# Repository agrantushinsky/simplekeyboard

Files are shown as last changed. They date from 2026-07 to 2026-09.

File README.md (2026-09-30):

# simplekeyboard: 60% Mechanical Keyboard PCB
## Overview
A custom 60% mechanical keyboard 2-layer PCB built around an STM32 microcontroller and USB-C connectivity. The design utilizes I2C IO expanders to simplify matrix trace routing across the board. 

## Current Status (WIP)
Hardware bring-up is actively underway. I identified an error that swapped the SCL and SDA lines on one of the IO expanders. The next step is performing a physical trace bodge to fix the bus so I can finish validating the matrix polling logic.

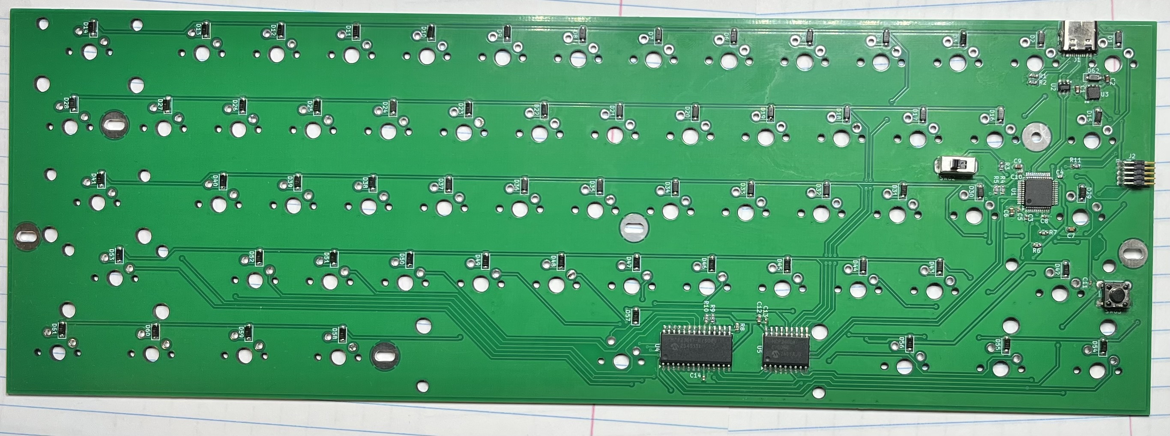
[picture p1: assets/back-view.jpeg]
Back View of PCB


## Schematics
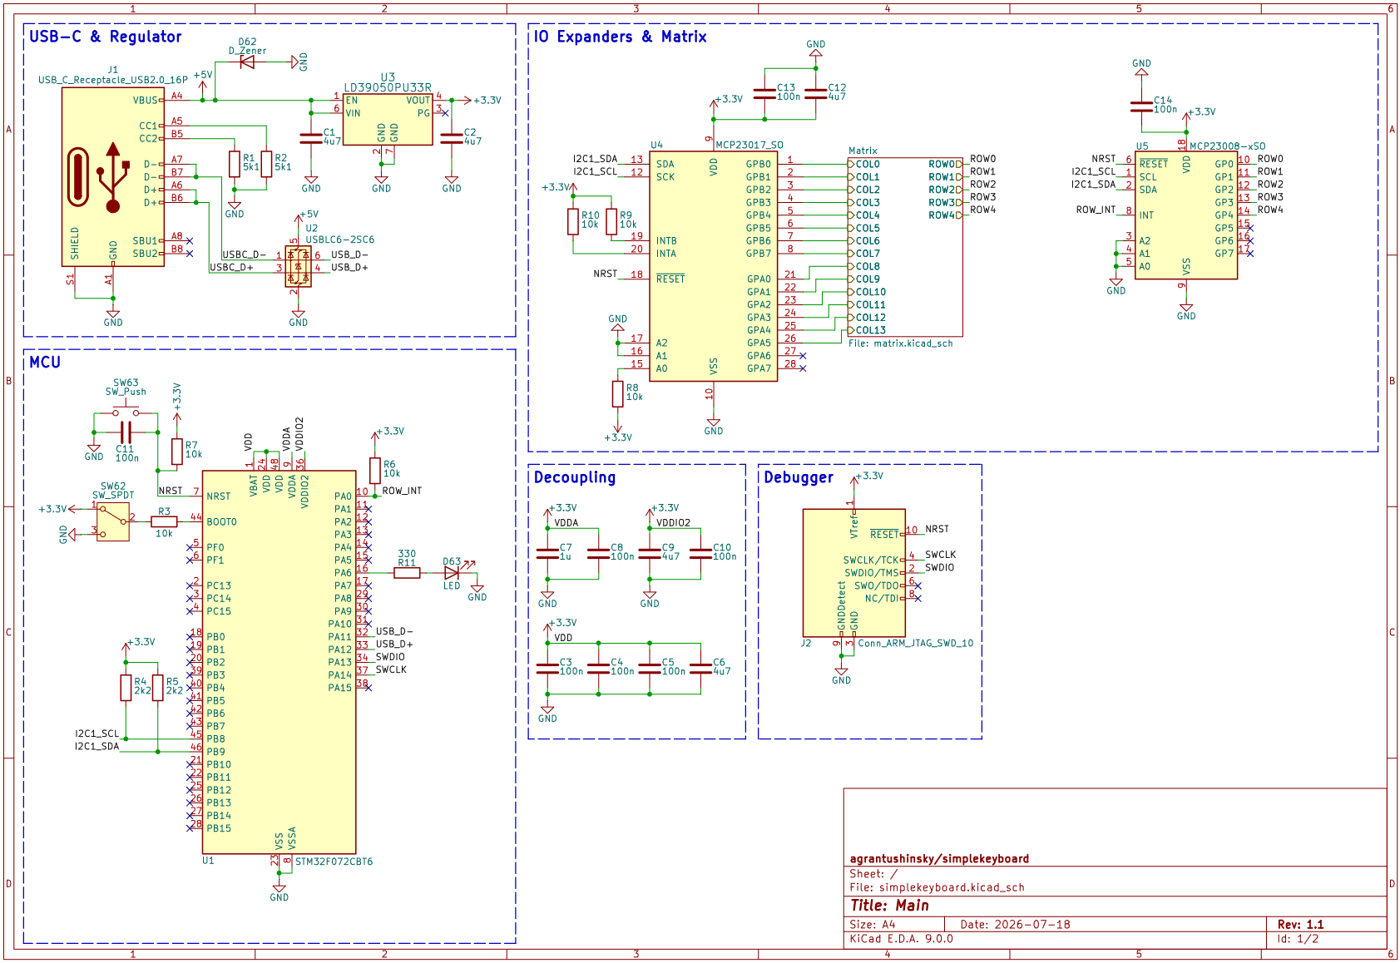
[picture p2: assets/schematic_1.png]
Schematic Snippet 1

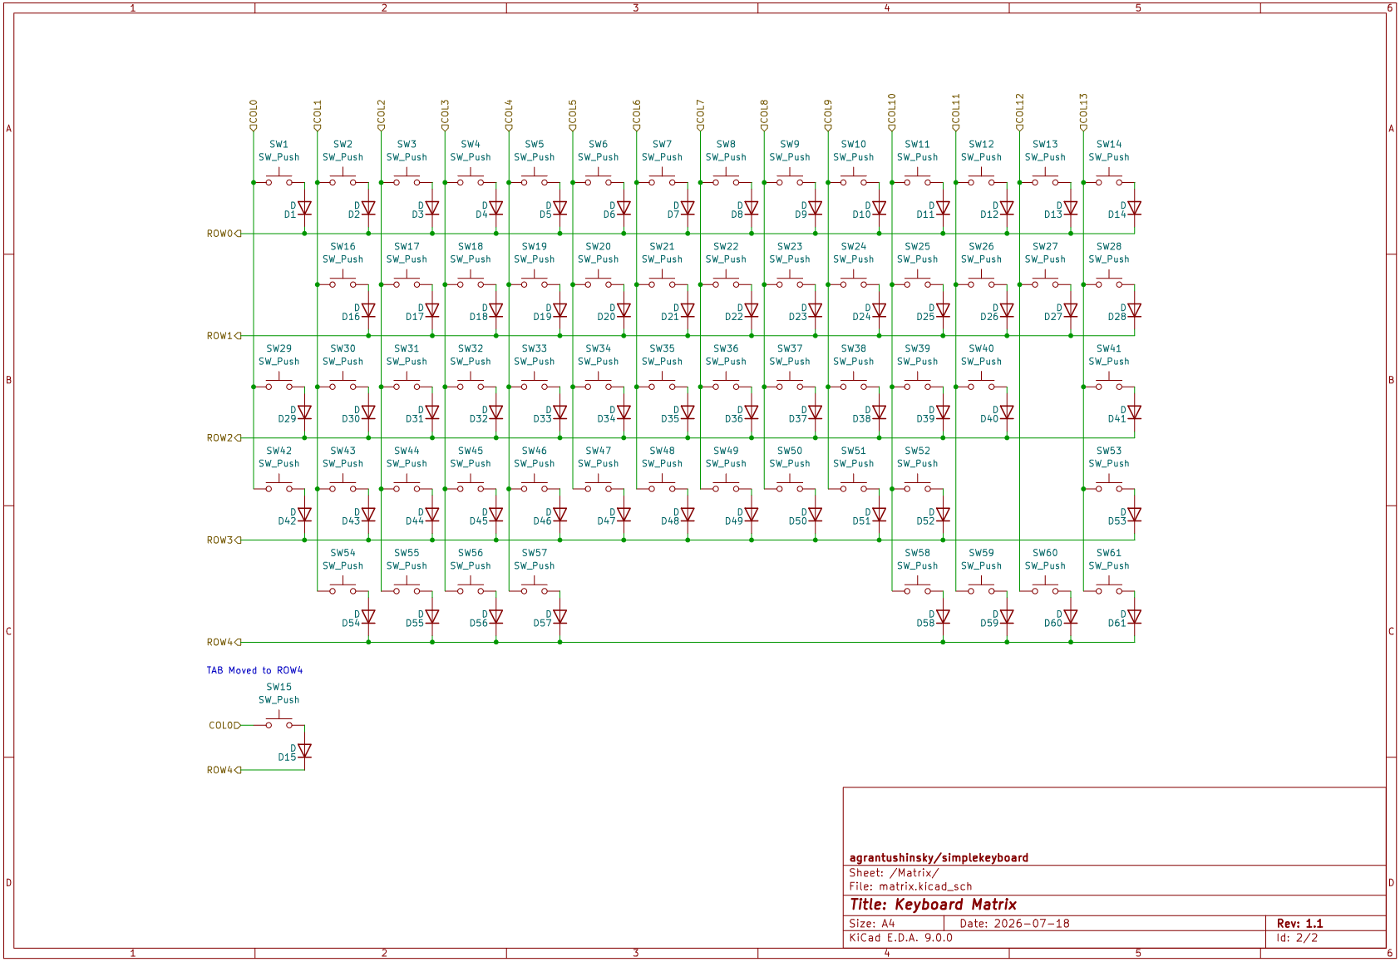
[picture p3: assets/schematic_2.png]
Schematic Snippet 2

*View the full schematic PDF: [schematics.pdf](assets/schematics.pdf)*

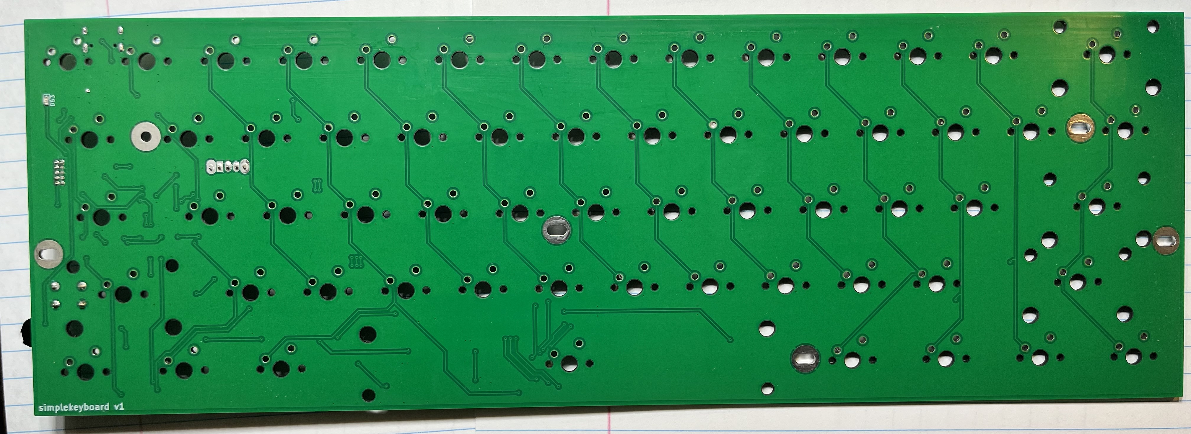
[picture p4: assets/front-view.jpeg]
Top View of PCB


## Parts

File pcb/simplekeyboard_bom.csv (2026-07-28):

Reference | Qty | Value | DNP | Exclude from BOM | Exclude from Board | Footprint | Datasheet | Manufacturer Part Number
C1,C2,C6,C9,C12 | 5 | 4u7 |  |  |  | Capacitor_SMD:C_0603_1608Metric | ~ | GRM188R61E475KE11D
C3,C4,C5,C8,C10,C11,C13,C14 | 8 | 100n |  |  |  | Capacitor_SMD:C_0402_1005Metric | ~ | GCM155R71H104KE02D
C7 | 1 | 1u |  |  |  | Capacitor_SMD:C_0603_1608Metric | ~ | GCM188R71E105KA64J
D1,D2,D3,D4,D5,D6,D7,D8,D9,D10,D11,D12,D13,D14,D15,D16,D17,D18,D19,D20,D21,D22,D23,D24,D25,D26,D27,D28,D29,D30,D31,D32,D33,D34,D35,D36,D37,D38,D39,D40,D41,D42,D43,D44,D45,D46,D47,D48,D49,D50,D51,D52,D53,D54,D55,D56,D57,D58,D59,D60,D61 | 61 | D |  |  |  | Diode_SMD:D_SOD-123 | ~ | 1N4148W-TP
D62 | 1 | D_Zener |  |  |  | Diode_SMD:D_SOD-123 | ~ | MMSZ5233BT1G
D63 | 1 | LED |  |  |  | LED_SMD:LED_0603_1608Metric | ~ | LTST-C191KFKT
H1 | 10 | MountingHole_Pad |  | Excluded from BOM |  | Keyboard_Mounts:2.5mm | ~ | 50M020040P008B
H2,H3,H4,H5,H6 | 10 | MountingHole_Pad |  | Excluded from BOM |  | Keyboard_Mounts:2.5mm_Oblong | ~ | 50M020040P006B
J1 | 1 | USB_C_Receptacle_USB2.0_16P |  |  |  | Connector_USB:USB_C_Receptacle_HRO_TYPE-C-31-M-12 | https://www.usb.org/sites/default/files/documents/usb_type-c.zip | UJ20-C-H-G-SMT-2A-P16-TR
J2 | 1 | Conn_ARM_JTAG_SWD_10 |  |  |  | Connector_PinHeader_1.27mm:PinHeader_2x05_P1.27mm_Horizontal | http://infocenter.arm.com/help/topic/com.arm.doc.ddi0314h/DDI0314H_coresight_components_trm.pdf | FTSH-105-01-F-D-RA
R1,R2 | 2 | 5k1 |  |  |  | Resistor_SMD:R_0603_1608Metric | ~ | RC0603FR-075K1L
R3,R6,R7,R8,R9,R10 | 6 | 10k |  |  |  | Resistor_SMD:R_0603_1608Metric | ~ | RC0603FR-0710KL
R4,R5 | 2 | 2k2 |  |  |  | Resistor_SMD:R_0603_1608Metric | ~ | RC0603FR-072K2L
R11 | 1 | 330 |  |  |  | Resistor_SMD:R_0603_1608Metric | ~ | RC0603FR-07330RL
SW1,SW2,SW3,SW4,SW5,SW6,SW7,SW8,SW9,SW10,SW11,SW12,SW13,SW16,SW17,SW18,SW19,SW20,SW21,SW22,SW23,SW24,SW25,SW26,SW27,SW30,SW31,SW32,SW33,SW34,SW35,SW36,SW37,SW38,SW39,SW40,SW43,SW44,SW45,SW46,SW47,SW48,SW49,SW50,SW51,SW52 | 46 | SW_Push |  |  |  | ai03_MX:MX-Solderable-1U | ~
SW14 | 1 | SW_Push |  |  |  | ai03_MX:MX-Solderable-2U | ~
SW15,SW28 | 2 | SW_Push |  |  |  | ai03_MX:MX-Solderable-1.5U | ~
SW29 | 1 | SW_Push |  |  |  | ai03_MX:MX-Solderable-1.75U | ~
SW41,SW42 | 2 | SW_Push |  |  |  | ai03_MX:MX-Solderable-2.25U | ~
SW53 | 1 | SW_Push |  |  |  | ai03_MX:MX-Solderable-2.75U | ~
SW54,SW55,SW56,SW58,SW59,SW60,SW61 | 7 | SW_Push |  |  |  | ai03_MX:MX-Solderable-1.25U | ~
SW57 | 1 | SW_Push |  |  |  | ai03_MX:MX-Solderable-6.25U | ~
SW62 | 1 | SW_SPDT |  |  |  | Button_Switch_THT:SW_Slide_SPDT_Straight_CK_OS102011MS2Q | ~ | OS102011MS2QN1
SW63 | 1 | SW_Push |  |  |  | Button_Switch_THT:SW_PUSH_6mm | ~ | PTS645SL50-2 LFS
U1 | 1 | STM32F072CBT6 |  |  |  | Package_QFP:LQFP-48_7x7mm_P0.5mm | https://www.st.com/resource/en/datasheet/stm32f072cb.pdf | STM32F072CBT6
U2 | 1 | USBLC6-2SC6 |  |  |  | Package_TO_SOT_SMD:SOT-23-6 | https://www.st.com/resource/en/datasheet/usblc6-2.pdf | USBLC6-2SC6
U3 | 1 | LD39050PU33R |  |  |  | Keyboard_Power:DFN6_3X3_STM | https://www.st.com/resource/en/datasheet/ld39050.pdf | LD39050PU33R
U4 | 1 | MCP23017_SO |  |  |  | Package_SO:SOIC-28W_7.5x17.9mm_P1.27mm | https://ww1.microchip.com/downloads/aemDocuments/documents/APID/ProductDocuments/DataSheets/MCP23017-Data-Sheet-DS20001952.pdf | MCP23017T-E/SO
U5 | 1 | MCP23008-xSO |  |  |  | Package_SO:SOIC-18W_7.5x11.6mm_P1.27mm | http://ww1.microchip.com/downloads/en/DeviceDoc/MCP23008-MCP23S08-Data-Sheet-20001919F.pdf | MCP23008T-E/SO

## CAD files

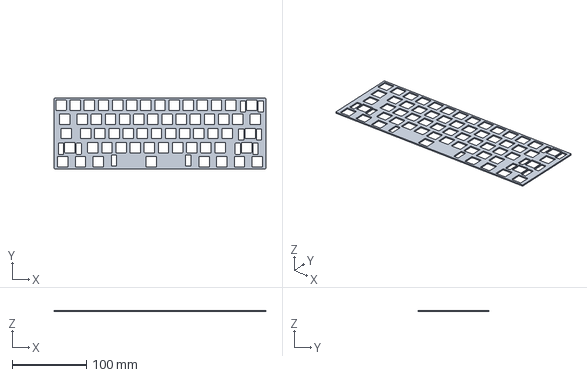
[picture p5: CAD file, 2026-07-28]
cad/plate.FCStd
285.8 x 95.2 x 1.50 mm

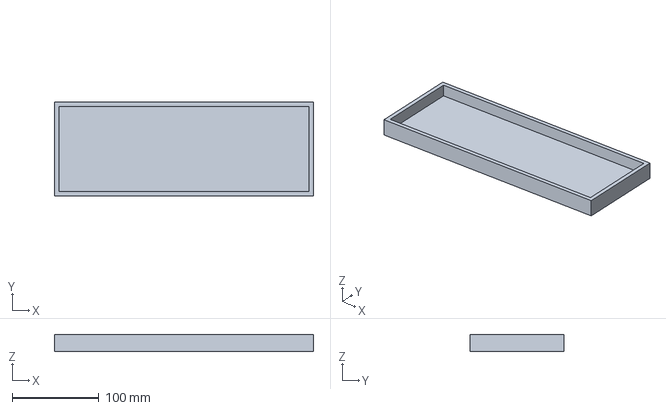
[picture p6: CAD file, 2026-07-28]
cad/case.FCStd
299.1 x 108.6 x 20.0 mm

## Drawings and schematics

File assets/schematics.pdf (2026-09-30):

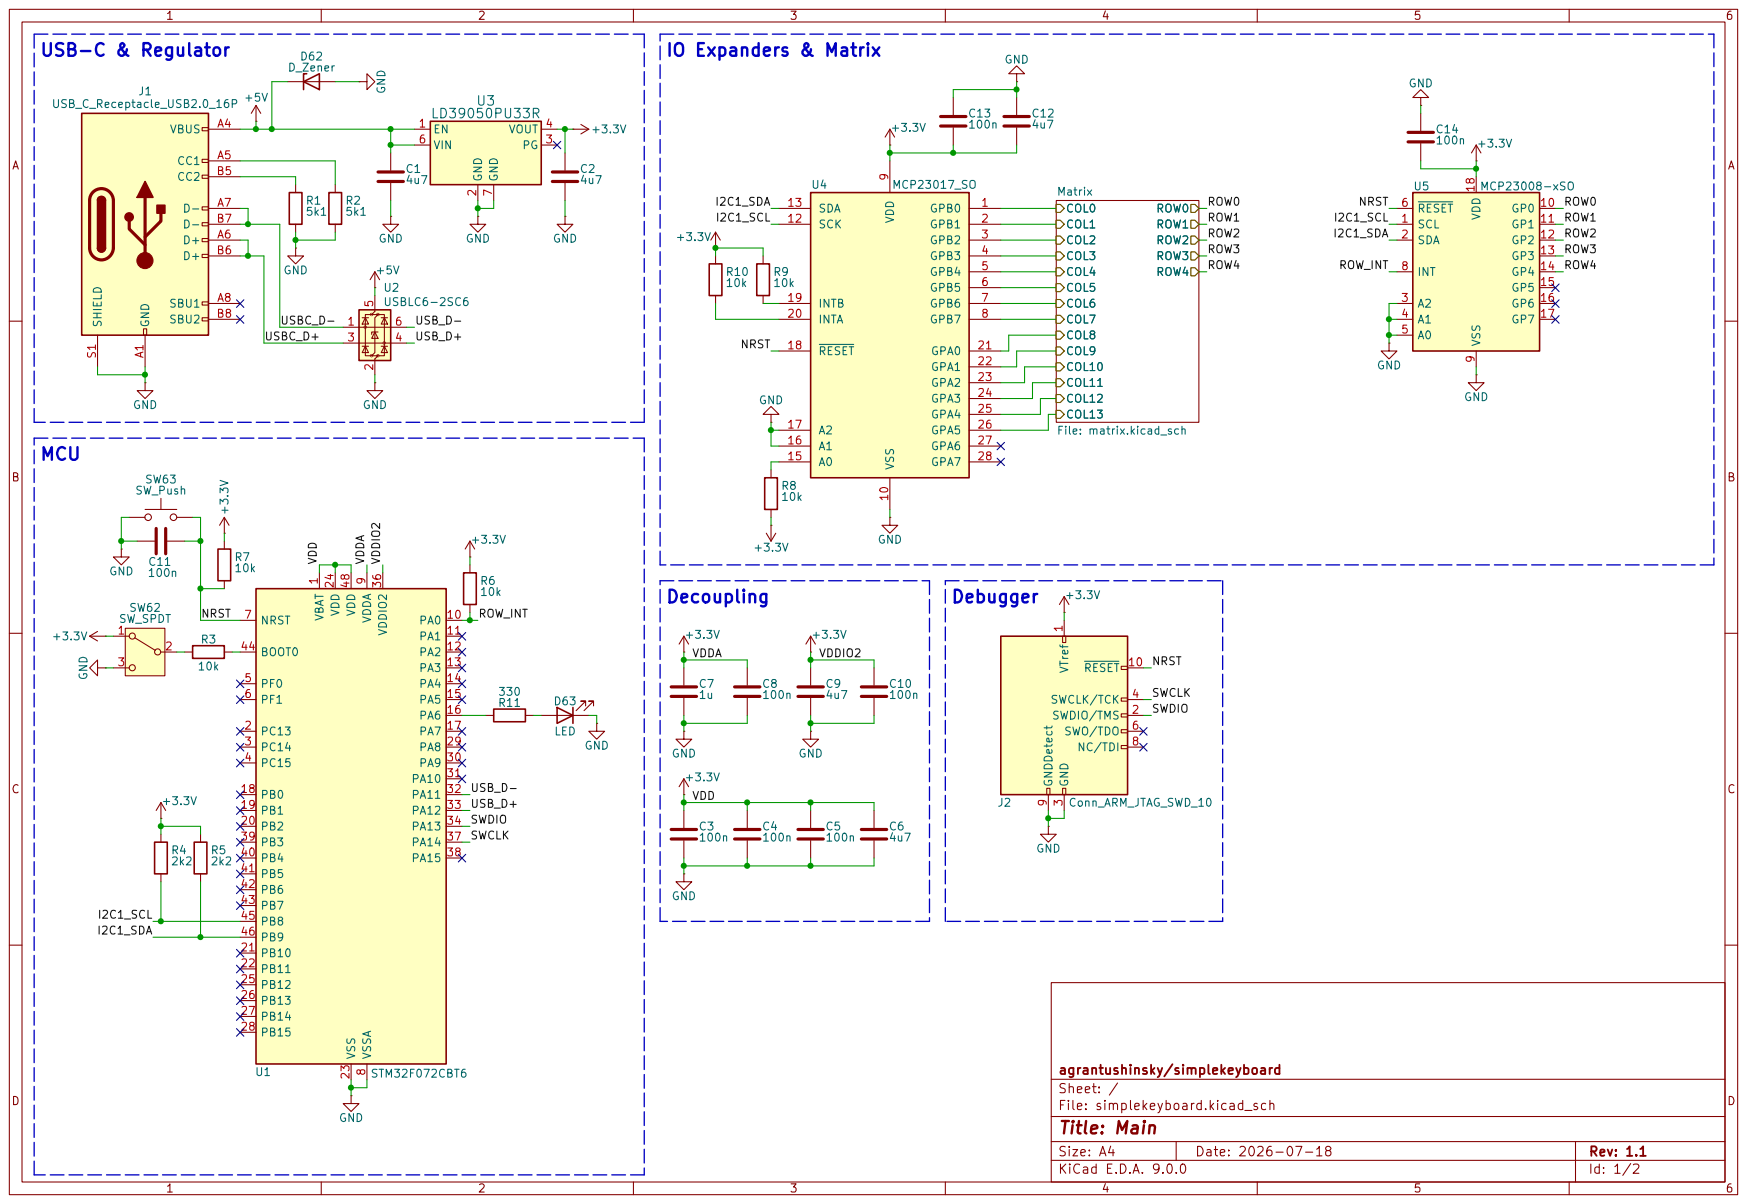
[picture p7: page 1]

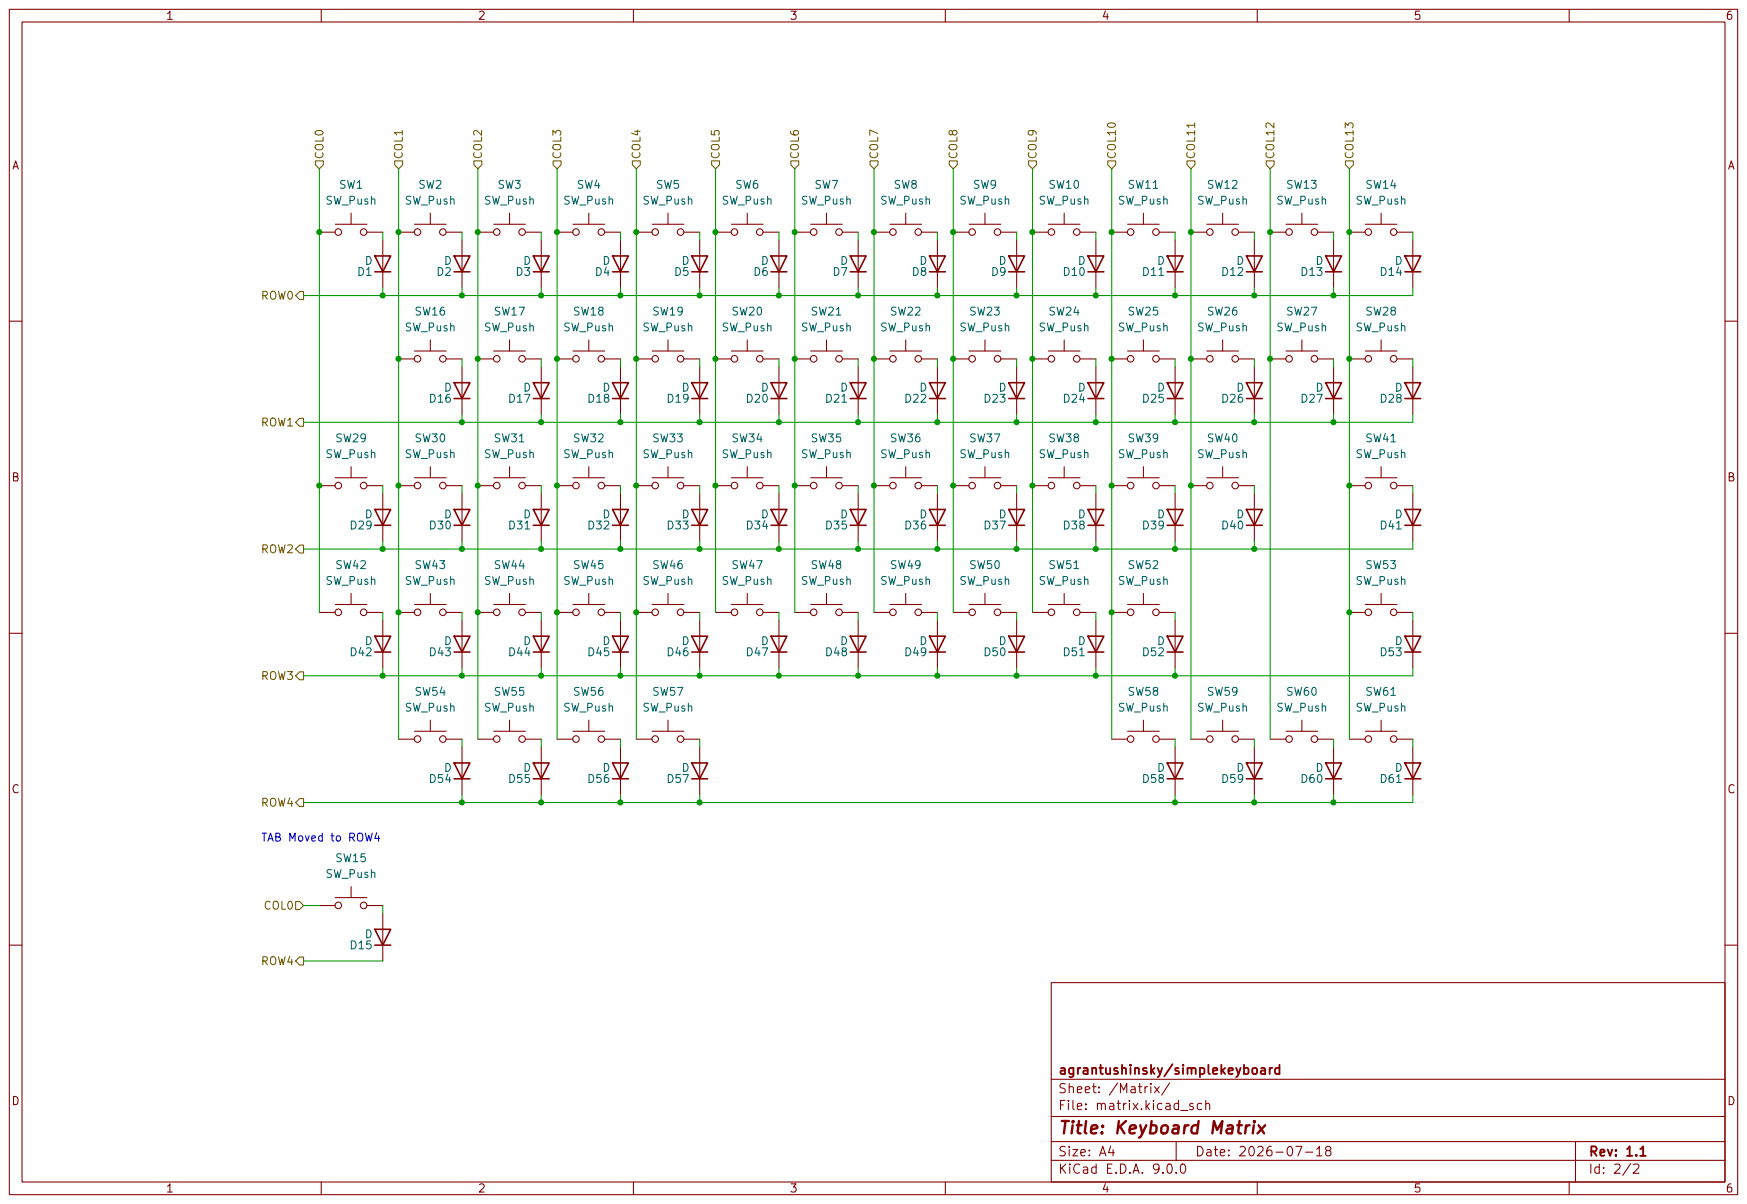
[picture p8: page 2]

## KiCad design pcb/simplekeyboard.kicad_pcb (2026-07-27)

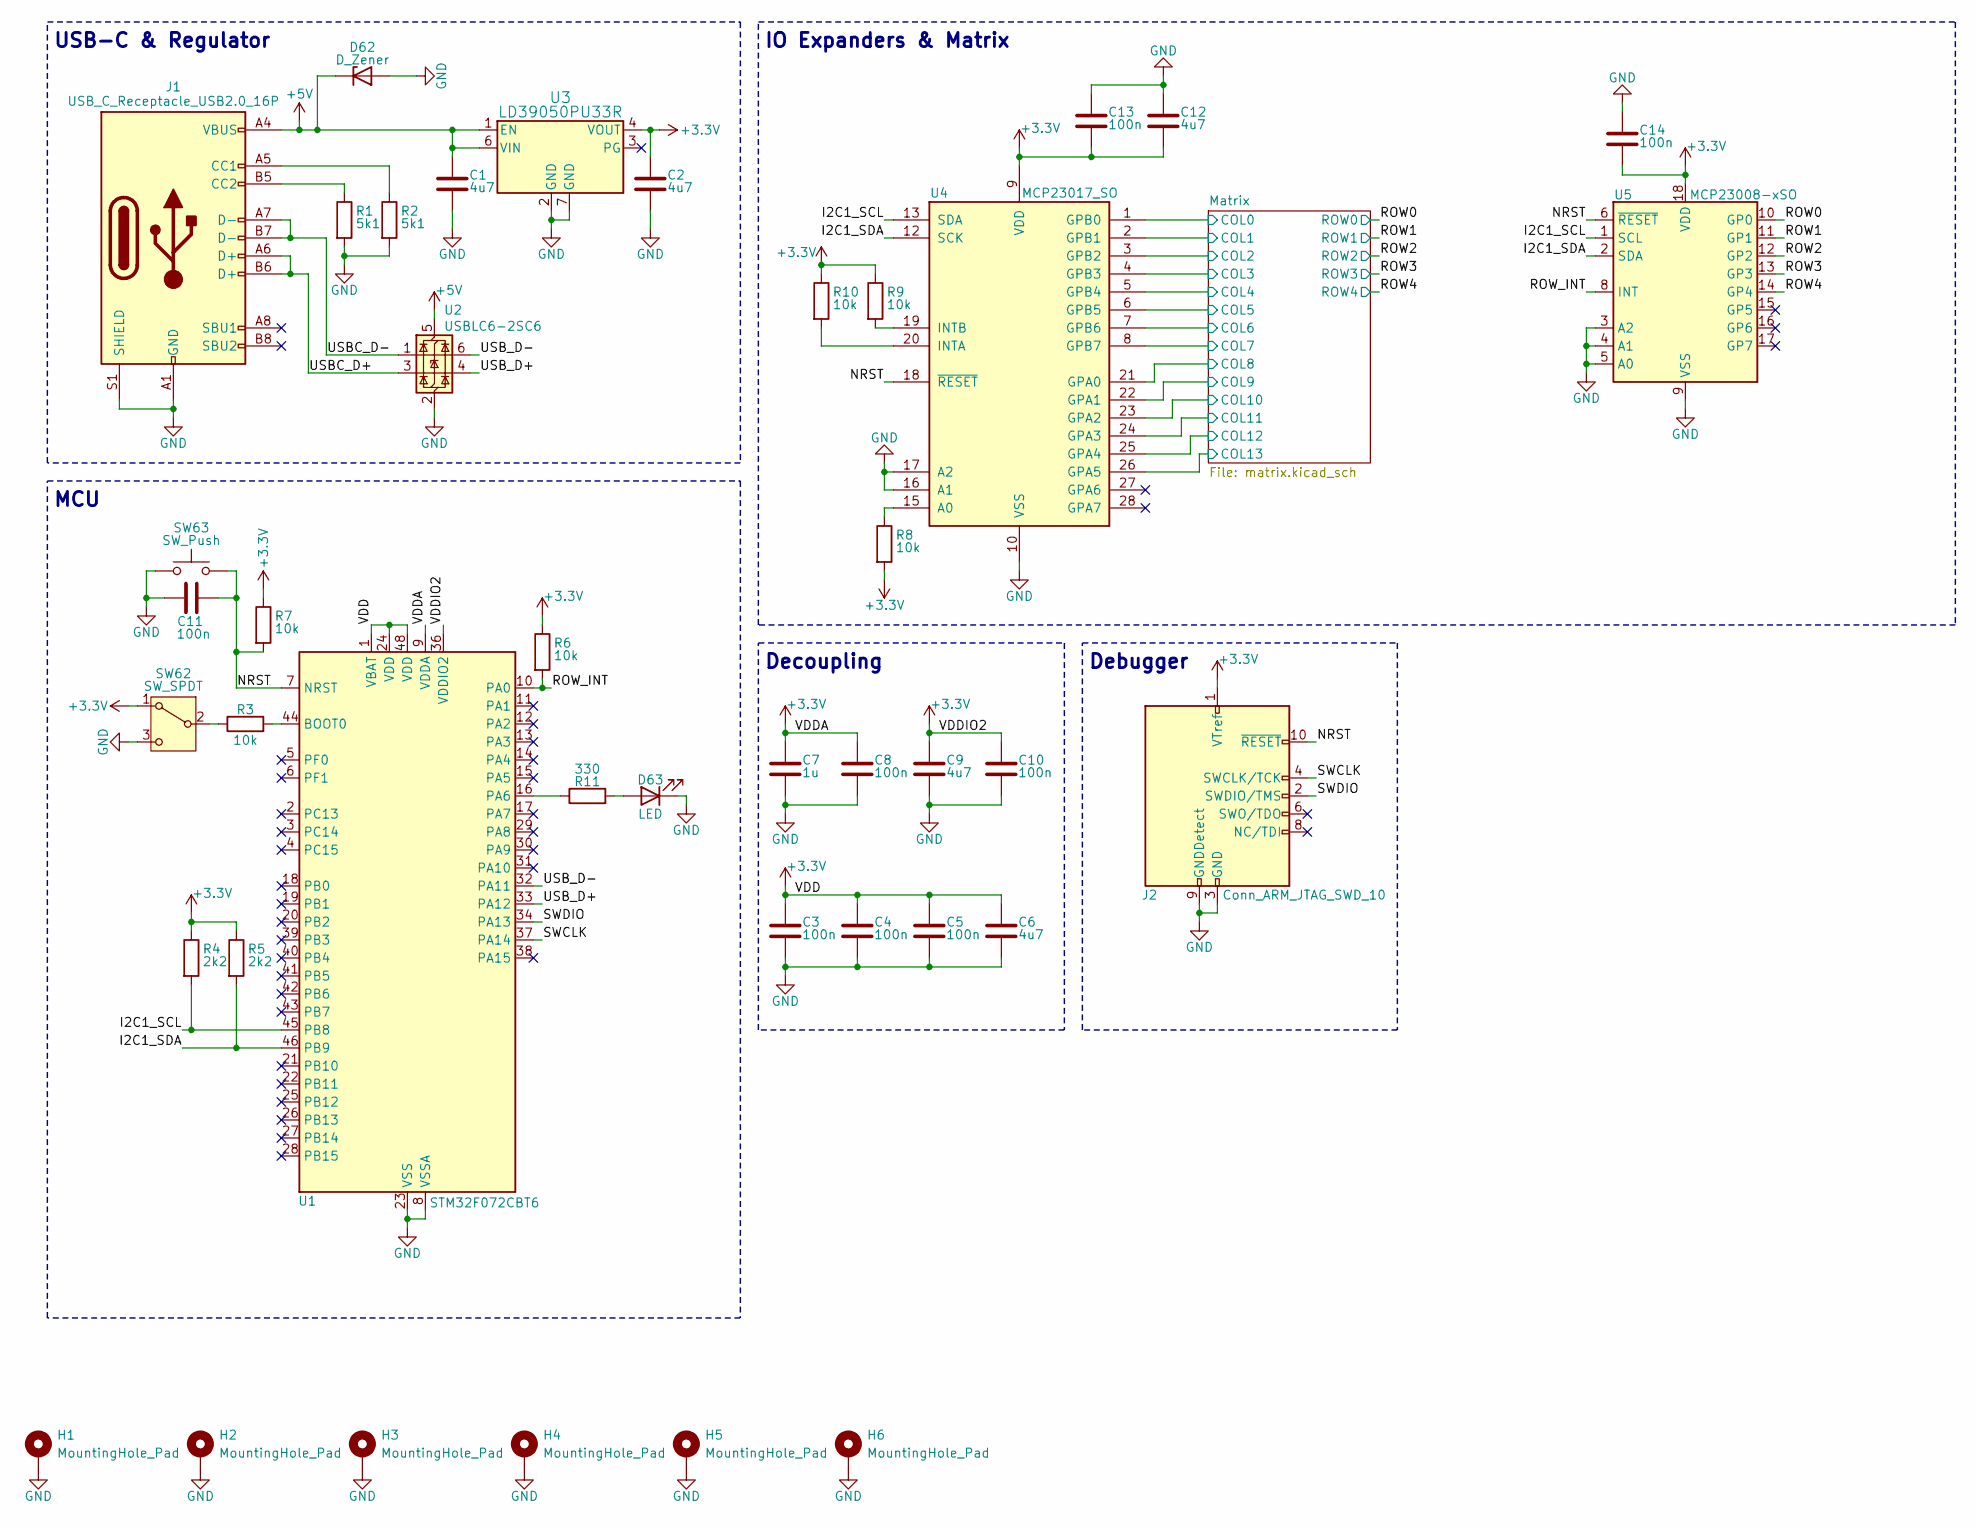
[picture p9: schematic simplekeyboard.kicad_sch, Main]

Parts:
C1, C2, C6, C9, C12: 4u7; C_0603_1608Metric
C3, C4, C5, C8, C10, C11, C13, C14: 100n; C_0402_1005Metric
C7: 1u; C_0603_1608Metric
D62: D_Zener; D_SOD-123
D63: LED; LED_0603_1608Metric
H1: MountingHole_Pad; 2.5mm
H2, H3, H4, H5, H6: MountingHole_Pad; 2.5mm_Oblong
J1: USB_C_Receptacle_USB2.0_16P; USB_C_Receptacle_HRO_TYPE-C-31-M-12
J2: Conn_ARM_JTAG_SWD_10; PinHeader_2x05_P1.27mm_Horizontal
R1, R2: 5k1; R_0603_1608Metric
R3, R6, R7, R8, R9, R10: 10k; R_0603_1608Metric
R4, R5: 2k2; R_0603_1608Metric
R11: 330; R_0603_1608Metric
SW62: SW_SPDT; SW_Slide_SPDT_Straight_CK_OS102011MS2Q
SW63: SW_Push; SW_PUSH_6mm
U1: STM32F072CBT6; LQFP-48_7x7mm_P0.5mm
U2: USBLC6-2SC6; SOT-23-6
U3: LD39050PU33R; DFN6_3X3_STM
U4: MCP23017_SO; SOIC-28W_7.5x17.9mm_P1.27mm
U5: MCP23008-xSO; SOIC-18W_7.5x11.6mm_P1.27mm

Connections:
+3.3V: C2.1, C3.1, C4.1, C5.1, C6.1, C7.1, C8.1, C9.1, C10.1, C12.2, C13.2, C14.2, J2.1 (VTref), R4.1, R5.1, R6.1, R7.1, R8.2, R9.1, R10.1, SW62.1 (A), U1.1 (VBAT), U1.9 (VDDA), U1.24 (VDD), U1.36 (VDDIO2), U1.48 (VDD), U3.4 (VOUT), U4.9 (VDD), U5.18 (VDD)
+5V: C1.1, D62.1 (K), J1.A4 (VBUS), J1.A9 (VBUS), J1.B4 (VBUS), J1.B9 (VBUS), U2.5 (VBUS), U3.1 (EN), U3.6 (VIN)
/I2C1_SCL: R4.2, U1.45 (PB8), U4.13 (SDA), U5.1 (SCL)
/I2C1_SDA: R5.2, U1.46 (PB9), U4.12 (SCK), U5.2 (SDA)
/Matrix/COL0: U4.1 (GPB0); also elsewhere on the board
/Matrix/COL1: U4.2 (GPB1); also elsewhere on the board
/Matrix/COL2: U4.3 (GPB2); also elsewhere on the board
/Matrix/COL3: U4.4 (GPB3); also elsewhere on the board
/Matrix/COL4: U4.5 (GPB4); also elsewhere on the board
/Matrix/COL5: U4.6 (GPB5); also elsewhere on the board
/Matrix/COL6: U4.7 (GPB6); also elsewhere on the board
/Matrix/COL7: U4.8 (GPB7); also elsewhere on the board
/Matrix/COL8: U4.21 (GPA0); also elsewhere on the board
/Matrix/COL9: U4.22 (GPA1); also elsewhere on the board
/Matrix/COL10: U4.23 (GPA2); also elsewhere on the board
/Matrix/COL11: U4.24 (GPA3); also elsewhere on the board
/Matrix/COL12: U4.25 (GPA4); also elsewhere on the board
/Matrix/COL13: U4.26 (GPA5); also elsewhere on the board
/NRST: C11.2, J2.10 (~RESET), R7.2, SW63.2, U1.7 (NRST), U4.18 (~RESET), U5.6 (~RESET)
/ROW0: U5.10 (GP0); also elsewhere on the board
/ROW1: U5.11 (GP1); also elsewhere on the board
/ROW2: U5.12 (GP2); also elsewhere on the board
/ROW3: U5.13 (GP3); also elsewhere on the board
/ROW4: U5.14 (GP4); also elsewhere on the board
/ROW_INT: R6.2, U1.10 (PA0), U5.8 (INT)
/SWCLK: J2.4 (SWCLK/TCK), U1.37 (PA14)
/SWDIO: J2.2 (SWDIO/TMS), U1.34 (PA13)
/USBC_D+: J1.A6 (D+), J1.B6 (D+), U2.3 (I/O2)
/USBC_D-: J1.A7 (D-), J1.B7 (D-), U2.1 (I/O1)
/USB_D+: U1.33 (PA12), U2.4 (I/O2)
/USB_D-: U1.32 (PA11), U2.6 (I/O1)
GND: C1.2, C2.2, C3.2, C4.2, C5.2, C6.2, C7.2, C8.2, C9.2, C10.2, C11.1, C12.1, C13.1, C14.1, D62.2 (A), D63.1 (K), H1.1, H2.1, H3.1, H4.1, H5.1, H6.1, J1.A1 (GND), J1.A12 (GND), J1.B1 (GND), J1.B12 (GND), J1.S1 (SHIELD), J2.3 (GND), J2.5 (GND), J2.9 (GNDDetect), R1.2, R2.2, SW62.3 (C), SW63.1, U1.8 (VSSA), U1.23 (VSS), U1.35 (VSS), U1.47 (VSS), U2.2 (GND), U3.2 (GND), U3.7 (GND), U4.10 (VSS), U4.16 (A1), U4.17 (A2), U5.3 (A2), U5.4 (A1), U5.5 (A0), U5.9 (VSS)
unnamed: D63.2 (A), R11.2
unnamed: J1.A5 (CC1), R2.1
unnamed: J1.B5 (CC2), R1.1
unnamed: R3.1, SW62.2 (B)
unnamed: R3.2, U1.44 (BOOT0)
unnamed: R11.1, U1.16 (PA6)
unnamed: R8.1, U4.15 (A0)
unnamed: R10.2, U4.20 (INTA)
unnamed: R9.2, U4.19 (INTB)

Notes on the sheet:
Decoupling
MCU
IO Expanders & Matrix
USB-C & Regulator
Debugger

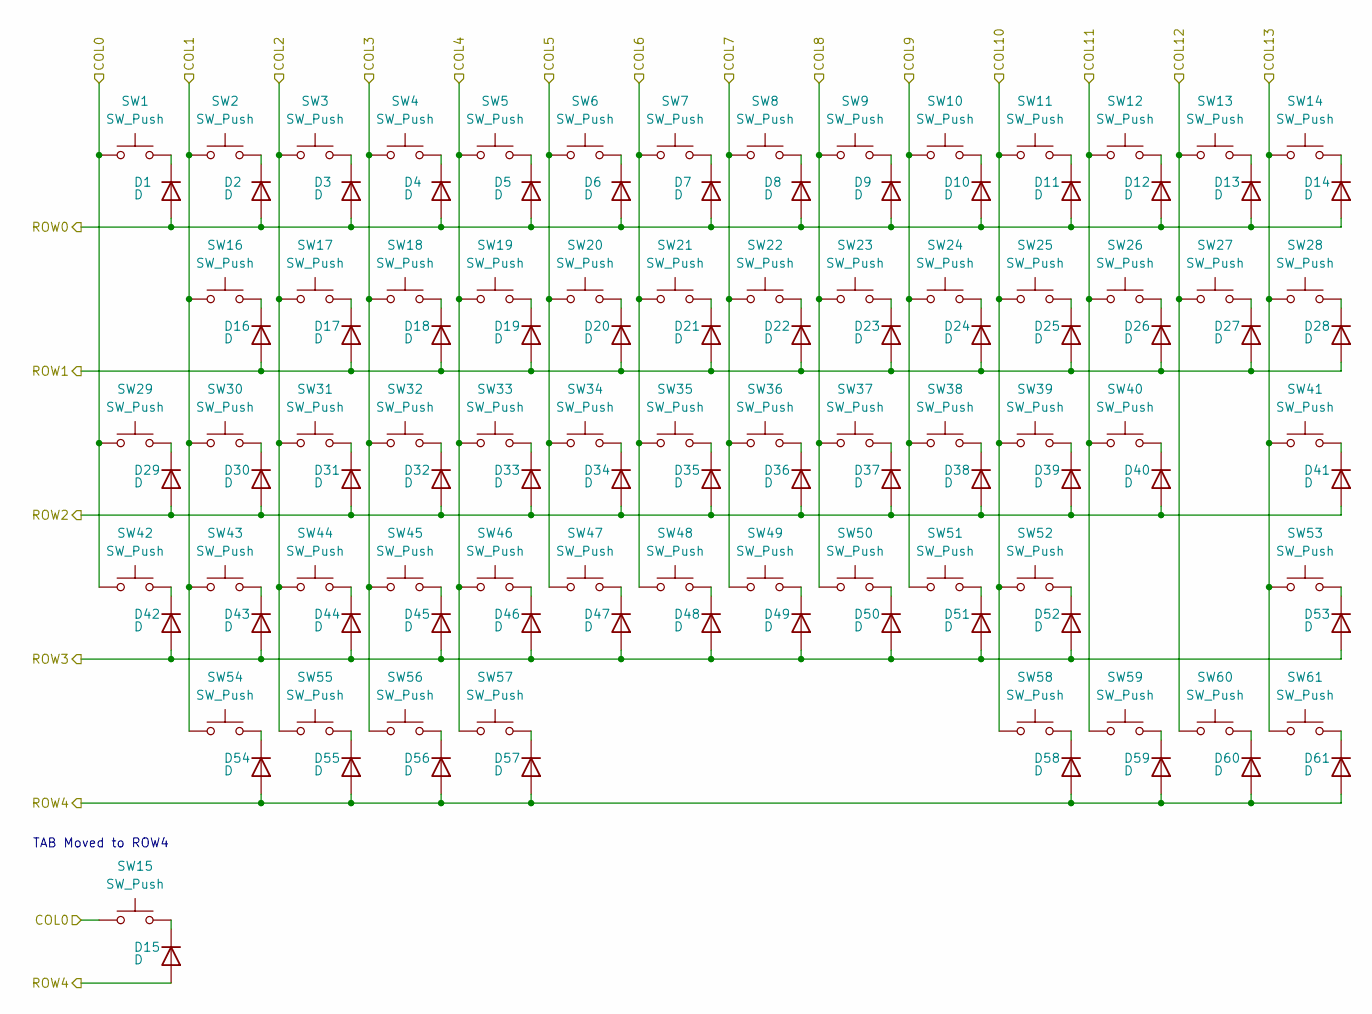
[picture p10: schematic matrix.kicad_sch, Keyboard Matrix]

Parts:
D1, D2, D3, D4, D5, D6, D7, D8, D9, D10, D11, D12, D13, D14, D15, D16, D17, D18, D19, D20, D21, D22, D23, D24, D25, D26, D27, D28, D29, D30, D31, D32, D33, D34, D35, D36, D37, D38, D39, D40, D41, D42, D43, D44, D45, D46, D47, D48, D49, D50, D51, D52, D53, D54, D55, D56, D57, D58, D59, D60, D61: D; D_SOD-123
SW1, SW2, SW3, SW4, SW5, SW6, SW7, SW8, SW9, SW10, SW11, SW12, SW13, SW16, SW17, SW18, SW19, SW20, SW21, SW22, SW23, SW24, SW25, SW26, SW27, SW30, SW31, SW32, SW33, SW34, SW35, SW36, SW37, SW38, SW39, SW40, SW43, SW44, SW45, SW46, SW47, SW48, SW49, SW50, SW51, SW52: SW_Push; MX-Solderable-1U
SW14: SW_Push; MX-Solderable-2U
SW15, SW28: SW_Push; MX-Solderable-1.5U
SW29: SW_Push; MX-Solderable-1.75U
SW41, SW42: SW_Push; MX-Solderable-2.25U
SW53: SW_Push; MX-Solderable-2.75U
SW54, SW55, SW56, SW58, SW59, SW60, SW61: SW_Push; MX-Solderable-1.25U
SW57: SW_Push; MX-Solderable-6.25U-ReversedStabilizers

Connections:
/Matrix/COL0: SW1.1, SW15.1, SW29.1, SW42.1; also elsewhere on the board
/Matrix/COL1: SW2.1, SW16.1, SW30.1, SW43.1, SW54.1; also elsewhere on the board
/Matrix/COL2: SW3.1, SW17.1, SW31.1, SW44.1, SW55.1; also elsewhere on the board
/Matrix/COL3: SW4.1, SW18.1, SW32.1, SW45.1, SW56.1; also elsewhere on the board
/Matrix/COL4: SW5.1, SW19.1, SW33.1, SW46.1, SW57.1; also elsewhere on the board
/Matrix/COL5: SW6.1, SW20.1, SW34.1, SW47.1; also elsewhere on the board
/Matrix/COL6: SW7.1, SW21.1, SW35.1, SW48.1; also elsewhere on the board
/Matrix/COL7: SW8.1, SW22.1, SW36.1, SW49.1; also elsewhere on the board
/Matrix/COL8: SW9.1, SW23.1, SW37.1, SW50.1; also elsewhere on the board
/Matrix/COL9: SW10.1, SW24.1, SW38.1, SW51.1; also elsewhere on the board
/Matrix/COL10: SW11.1, SW25.1, SW39.1, SW52.1, SW58.1; also elsewhere on the board
/Matrix/COL11: SW12.1, SW26.1, SW40.1, SW59.1; also elsewhere on the board
/Matrix/COL12: SW13.1, SW27.1, SW60.1; also elsewhere on the board
/Matrix/COL13: SW14.1, SW28.1, SW41.1, SW53.1, SW61.1; also elsewhere on the board
/ROW0: D1.2 (A), D2.2 (A), D3.2 (A), D4.2 (A), D5.2 (A), D6.2 (A), D7.2 (A), D8.2 (A), D9.2 (A), D10.2 (A), D11.2 (A), D12.2 (A), D13.2 (A), D14.2 (A); also elsewhere on the board
/ROW1: D16.2 (A), D17.2 (A), D18.2 (A), D19.2 (A), D20.2 (A), D21.2 (A), D22.2 (A), D23.2 (A), D24.2 (A), D25.2 (A), D26.2 (A), D27.2 (A), D28.2 (A); also elsewhere on the board
/ROW2: D29.2 (A), D30.2 (A), D31.2 (A), D32.2 (A), D33.2 (A), D34.2 (A), D35.2 (A), D36.2 (A), D37.2 (A), D38.2 (A), D39.2 (A), D40.2 (A), D41.2 (A); also elsewhere on the board
/ROW3: D42.2 (A), D43.2 (A), D44.2 (A), D45.2 (A), D46.2 (A), D47.2 (A), D48.2 (A), D49.2 (A), D50.2 (A), D51.2 (A), D52.2 (A), D53.2 (A); also elsewhere on the board
/ROW4: D15.2 (A), D54.2 (A), D55.2 (A), D56.2 (A), D57.2 (A), D58.2 (A), D59.2 (A), D60.2 (A), D61.2 (A); also elsewhere on the board
unnamed: D1.1 (K), SW1.2
unnamed: D2.1 (K), SW2.2
unnamed: D3.1 (K), SW3.2
unnamed: D4.1 (K), SW4.2
unnamed: D5.1 (K), SW5.2
unnamed: D6.1 (K), SW6.2
unnamed: D7.1 (K), SW7.2
unnamed: D8.1 (K), SW8.2
unnamed: D9.1 (K), SW9.2
unnamed: D10.1 (K), SW10.2
unnamed: D11.1 (K), SW11.2
unnamed: D12.1 (K), SW12.2
unnamed: D13.1 (K), SW13.2
unnamed: D14.1 (K), SW14.2
unnamed: D15.1 (K), SW15.2
unnamed: D16.1 (K), SW16.2
unnamed: D17.1 (K), SW17.2
unnamed: D18.1 (K), SW18.2
unnamed: D19.1 (K), SW19.2
unnamed: D20.1 (K), SW20.2
unnamed: D21.1 (K), SW21.2
unnamed: D22.1 (K), SW22.2
unnamed: D23.1 (K), SW23.2
unnamed: D24.1 (K), SW24.2
unnamed: D25.1 (K), SW25.2
unnamed: D26.1 (K), SW26.2
unnamed: D27.1 (K), SW27.2
unnamed: D28.1 (K), SW28.2
unnamed: D29.1 (K), SW29.2
unnamed: D30.1 (K), SW30.2
unnamed: D31.1 (K), SW31.2
unnamed: D32.1 (K), SW32.2
unnamed: D33.1 (K), SW33.2
unnamed: D34.1 (K), SW34.2
unnamed: D35.1 (K), SW35.2
unnamed: D36.1 (K), SW36.2
unnamed: D37.1 (K), SW37.2
unnamed: D38.1 (K), SW38.2
unnamed: D39.1 (K), SW39.2
unnamed: D40.1 (K), SW40.2
unnamed: D41.1 (K), SW41.2
unnamed: D42.1 (K), SW42.2
unnamed: D43.1 (K), SW43.2
unnamed: D44.1 (K), SW44.2
unnamed: D45.1 (K), SW45.2
unnamed: D46.1 (K), SW46.2
unnamed: D47.1 (K), SW47.2
unnamed: D48.1 (K), SW48.2
unnamed: D49.1 (K), SW49.2
unnamed: D50.1 (K), SW50.2
unnamed: D51.1 (K), SW51.2
unnamed: D52.1 (K), SW52.2
unnamed: D53.1 (K), SW53.2
unnamed: D54.1 (K), SW54.2
unnamed: D55.1 (K), SW55.2
unnamed: D56.1 (K), SW56.2
unnamed: D57.1 (K), SW57.2
unnamed: D58.1 (K), SW58.2
unnamed: D59.1 (K), SW59.2
unnamed: D60.1 (K), SW60.2
unnamed: D61.1 (K), SW61.2

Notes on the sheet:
TAB Moved to ROW4

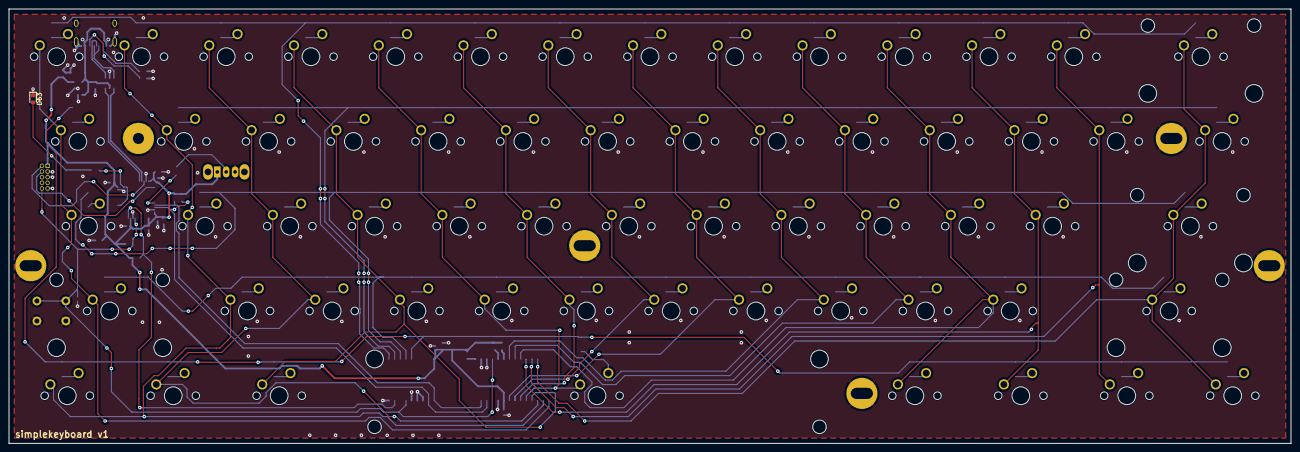
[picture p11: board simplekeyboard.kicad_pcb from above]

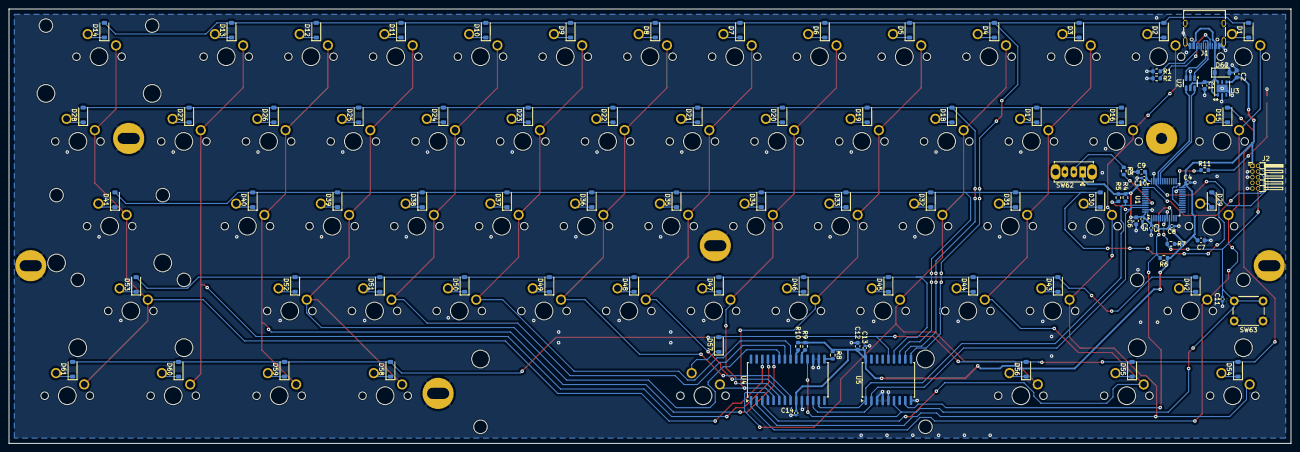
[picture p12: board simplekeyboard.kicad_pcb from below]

Board: 2 copper layers, 288.1 x 97.6 mm, 164 parts (96 on the bottom side), 102 nets.

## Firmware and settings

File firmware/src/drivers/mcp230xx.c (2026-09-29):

#include "drivers/mcp230xx.h"
#include "drivers/mcp230xx_regs.h"

static uint8_t resolve_register(mcp230xx_t *dev, mcp_port_t port, uint8_t reg_base_a) {
    if(dev->type == MCP_TYPE_23008) {
        switch (reg_base_a) {
            case MCP23017_IOCON:   return MCP23008_IOCON;
            case MCP23017_GPPUA:   return MCP23008_GPPU;
            case MCP23017_INTFA:   return MCP23008_INTF;
            case MCP23017_INTCAPA: return MCP23008_INTCAP;
            case MCP23017_GPIOA:   return MCP23008_GPIO;
            case MCP23017_OLATA:   return MCP23008_OLAT;
            default:               return reg_base_a;
        }
    }

    return (port == MCP_PORT_B) ? (reg_base_a + 1) : reg_base_a;
}

// =================================================================
// Generic read/write
// =================================================================
i2c_status_t mcp230xx_write_reg(mcp230xx_t *dev, uint8_t reg, uint8_t value) {
    return i2c_write_reg(dev->i2c_addr, reg, value);
}

i2c_status_t mcp230xx_read_reg(mcp230xx_t *dev, uint8_t reg, uint8_t *value) {
    return i2c_read_reg(dev->i2c_addr, reg, value);
}

// =================================================================
// Pin Configuration
// =================================================================
i2c_status_t mcp230xx_set_direction(mcp230xx_t *dev, mcp_port_t port, uint8_t mask) {
    uint8_t reg = resolve_register(dev, port, MCP_IODIRA);
    return mcp230xx_write_reg(dev, reg, mask);
}

i2c_status_t mcp230xx_set_input_polarity(mcp230xx_t *dev, mcp_port_t port, uint8_t mask) {
    uint8_t reg = resolve_register(dev, port, MCP_IPOLA);
    return mcp230xx_write_reg(dev, reg, mask);
}

i2c_status_t mcp230xx_set_enable_interrupt(mcp230xx_t *dev, mcp_port_t port, uint8_t mask) {
    uint8_t reg = resolve_register(dev, port, MCP_GPINTENA);
    return mcp230xx_write_reg(dev, reg, mask);
}

i2c_status_t mcp230xx_set_default_value(mcp230xx_t *dev, mcp_port_t port, uint8_t mask) {
    uint8_t reg = resolve_register(dev, port, MCP_DEFVALA);
    return mcp230xx_write_reg(dev, reg, mask);
}

i2c_status_t mcp230xx_set_interrupt_behaviour(mcp230xx_t *dev, mcp_port_t port, uint8_t mask) {
    uint8_t reg = resolve_register(dev, port, MCP_INTCONA);
    return mcp230xx_write_reg(dev, reg, mask);
}

i2c_status_t mcp230xx_set_config(mcp230xx_t *dev, uint8_t iocon_mask) {
    uint8_t reg = (dev->type == MCP_TYPE_23008) ? MCP23008_IOCON : MCP23017_IOCON;
    return mcp230xx_write_reg(dev, reg, iocon_mask);
}

i2c_status_t mcp230xx_set_pullups(mcp230xx_t *dev, mcp_port_t port, uint8_t mask) {
    uint8_t reg = resolve_register(dev, port, MCP_GPPUA);
    return mcp230xx_write_reg(dev, reg, mask);
}

// =================================================================
// Read-only data
// =================================================================
i2c_status_t mcp230xx_read_interrupt_flag(mcp230xx_t *dev, mcp_port_t port, uint8_t *mask) {
    uint8_t reg = resolve_register(dev, port, MCP_INTFA);
    return mcp230xx_read_reg(dev, reg, mask);
}

i2c_status_t mcp230xx_read_interrupt_capture(mcp230xx_t *dev, mcp_port_t port, uint8_t *mask) {
    uint8_t reg = resolve_register(dev, port, MCP_INTCAPA);
    return mcp230xx_read_reg(dev, reg, mask);
}

// =================================================================
// Port read/write
// =================================================================
i2c_status_t mcp230xx_write_port(mcp230xx_t *dev, mcp_port_t port, uint8_t value) {
    uint8_t reg = resolve_register(dev, port, MCP_OLATA);
    return mcp230xx_write_reg(dev, reg, value);
}

i2c_status_t mcp230xx_read_port(mcp230xx_t *dev, mcp_port_t port, uint8_t *value) {
    uint8_t reg = resolve_register(dev, port, MCP_GPIOA);
    return mcp230xx_read_reg(dev, reg, value);
}

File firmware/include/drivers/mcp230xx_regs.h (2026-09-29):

#ifndef MCP230XX_REGS_H
#define MCP230XX_REGS_H

// =============================================================================
// MCP23008 Register Map (8-bit / Single Port)
// =============================================================================
#define MCP23008_IODIR      0x00
#define MCP23008_IPOL       0x01
#define MCP23008_GPINTEN    0x02
#define MCP23008_DEFVAL     0x03
#define MCP23008_INTCON     0x04
#define MCP23008_IOCON      0x05
#define MCP23008_GPPU       0x06
#define MCP23008_INTF       0x07
#define MCP23008_INTCAP     0x08
#define MCP23008_GPIO       0x09
#define MCP23008_OLAT       0x0A

// =============================================================================
// MCP23017 Register Map (16-bit / BANK = 0 Interleaved)
// =============================================================================

// I/O Direction Registers (1 = Input, 0 = Output)
#define MCP23017_IODIRA     0x00
#define MCP23017_IODIRB     0x01

// Input Polarity Registers (1 = Inverted, 0 = Normal)
#define MCP23017_IPOLA      0x02
#define MCP23017_IPOLB      0x03

// Interrupt-on-Change Enable Registers (1 = Enable, 0 = Disable)
#define MCP23017_GPINTENA   0x04
#define MCP23017_GPINTENB   0x05

// Default Compare Value Registers for Interrupts
#define MCP23017_DEFVALA    0x06
#define MCP23017_DEFVALB    0x07

// Interrupt Control Registers (1 = Compare against DEFVAL, 0 = Compare against previous pin value)
#define MCP23017_INTCONA    0x08
#define MCP23017_INTCONB    0x09

// Configuration Register (0x0B is an alias for 0x0A in BANK = 0)
#define MCP23017_IOCON      0x0A
#define MCP23017_IOCON_ALIAS 0x0B

// Pull-Up Resistor Configuration Registers (1 = Enable 10k internal pull-up)
#define MCP23017_GPPUA      0x0C
#define MCP23017_GPPUB      0x0D

// Interrupt Flag Registers (Read-Only: 1 = Pin caused interrupt)
#define MCP23017_INTFA      0x0E
#define MCP23017_INTFB      0x0F

// Interrupt Capture Registers (Read-Only: Pin state at moment of interrupt)
#define MCP23017_INTCAPA    0x10
#define MCP23017_INTCAPB    0x11

// Port Registers (Read = Reads physical pins, Write = Writes output latch)
#define MCP23017_GPIOA      0x12
#define MCP23017_GPIOB      0x13

// Output Latch Registers (Read/Write = Output Latch values)
#define MCP23017_OLATA      0x14
#define MCP23017_OLATB      0x15

// =============================================================================
// IOCON Configuration Bit Masks (Shared across both MCP23008 & MCP23017)
// =============================================================================
#define MCP_IOCON_BANK      (1 << 7) // 1 = BANK 1 (Separated), 0 = BANK 0 (Interleaved - MCP23017 only)
#define MCP_IOCON_MIRROR    (1 << 6) // 1 = INTA and INTB connected internally (MCP23017 only)
#define MCP_IOCON_SEQOP     (1 << 5) // 1 = Sequential operation disabled, 0 = Enabled
#define MCP_IOCON_DISSLW    (1 << 4) // 1 = Slew rate control disabled, 0 = Enabled
#define MCP_IOCON_HAEN      (1 << 3) // Hardware Address Enable (SPI version only)
#define MCP_IOCON_ODR       (1 << 2) // 1 = INT pin Open-Drain, 0 = Active Driver
#define MCP_IOCON_INTPOL    (1 << 1) // 1 = Active-HIGH INT pin, 0 = Active-LOW INT pin

// =============================================================================
// Convenient Port A Aliases
// =============================================================================
#define MCP_IODIRA          MCP23017_IODIRA
#define MCP_IODIRB          MCP23017_IODIRB
#define MCP_IPOLA           MCP23017_IPOLA
#define MCP_IPOLB           MCP23017_IPOLB
#define MCP_GPINTENA        MCP23017_GPINTENA
#define MCP_GPINTENB        MCP23017_GPINTENB
#define MCP_DEFVALA         MCP23017_DEFVALA
#define MCP_DEFVALB         MCP23017_DEFVALB
#define MCP_INTCONA         MCP23017_INTCONA
#define MCP_INTCONB         MCP23017_INTCONB
#define MCP_GPPUA           MCP23017_GPPUA
#define MCP_GPPUB           MCP23017_GPPUB
#define MCP_INTFA           MCP23017_INTFA
#define MCP_INTFB           MCP23017_INTFB
#define MCP_INTCAPA         MCP23017_INTCAPA
#define MCP_INTCAPB         MCP23017_INTCAPB
#define MCP_GPIOA           MCP23017_GPIOA
#define MCP_GPIOB           MCP23017_GPIOB
#define MCP_OLATA           MCP23017_OLATA
#define MCP_OLATB           MCP23017_OLATB

#endif

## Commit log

2025-12-19 Create project
    [simplekeyboard.kicad_pcb, simplekeyboard.kicad_sch]
2025-12-20 Complete matrix and start MCU
    [matrix.kicad_sch, simplekeyboard.kicad_sch]
2026-01-09 Complete MCU USB and power
    [simplekeyboard.kicad_sch]
2026-01-09 Add reset and boot
    [simplekeyboard.kicad_sch]
2026-01-10 Finish board schematic
    [matrix.kicad_sch, simplekeyboard.kicad_sch]
2026-01-10 Start PCB layout
    [simplekeyboard.kicad_pcb, simplekeyboard.kicad_sch]
2026-01-10 Almost done PCB
    [simplekeyboard.kicad_pcb, simplekeyboard.kicad_sch]
2026-01-11 Route diodes
    [simplekeyboard.kicad_pcb]
2026-02-01 IO expanders in schematic
    [simplekeyboard.kicad_sch]
2026-02-01 Fix I2C bus
    [simplekeyboard.kicad_pcb, simplekeyboard.kicad_sch]
2026-02-01 Reverse diodes on keyboard matrix
    [matrix.kicad_sch, simplekeyboard.kicad_pcb]
2026-05-06 Finish and validate schematic
    [matrix.kicad_sch, simplekeyboard.kicad_sch]
2026-06-19 Clear board and add mounting holes
    [simplekeyboard.kicad_pcb, simplekeyboard.kicad_sch]
2026-06-20 Routing almost complete
    [simplekeyboard.kicad_pcb, simplekeyboard.kicad_sch]
2026-06-24 Finished routing and various fixes
    [matrix.kicad_sch, simplekeyboard.kicad_pcb, simplekeyboard.kicad_sch]
2026-07-13 Cleanup silkscreen
    [simplekeyboard.kicad_pcb, simplekeyboard.kicad_sch]
2026-07-17 Fixed critical mistake where CAPSLOCK and Tab were indistinguishable
    [matrix.kicad_sch, simplekeyboard.kicad_pcb, simplekeyboard.kicad_sch]
2026-07-18 Changed a few footrpints
    [simplekeyboard.kicad_pcb, simplekeyboard.kicad_sch]
2026-07-18 Back pour deleted by mistake
    [simplekeyboard.kicad_pcb]
2026-07-18 Changed schematic header
    [matrix.kicad_sch, simplekeyboard.kicad_sch]
2026-07-18 Moved cap
    [simplekeyboard.kicad_pcb]
2026-07-26 Added version marking
    [simplekeyboard.kicad_pcb]
2026-07-26 Added ground pad via on DFN
    [simplekeyboard.kicad_pcb]
2026-07-27 Changed spacebar to use reversed stabilizers
    [matrix.kicad_sch, simplekeyboard.kicad_pcb]
2026-07-28 Started cad. Added BOM
    [case.FCStd, plate.FCStd, simplekeyboard_bom.csv]
2026-07-29 MCP230xx drivers
2026-09-06 FreeRTOS working with heartbeat LED
2026-09-29 Fixed diode orientation and SDA/SCL
    [matrix.kicad_sch, simplekeyboard.kicad_sch]
